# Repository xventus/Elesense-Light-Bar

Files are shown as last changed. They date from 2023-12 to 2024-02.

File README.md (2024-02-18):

# LAMP

Elesense Light Bar is a monitor lamp from [kickstarter](https://www.kickstarter.com/projects/elesense/elesense-computer-monitor-light-bar). Because of the need to control it using a web interface or script and also out of curiosity how it works, this project was created. Take a screwdriver and an anlyzer and see how it works.....  

<table>
    <tr>
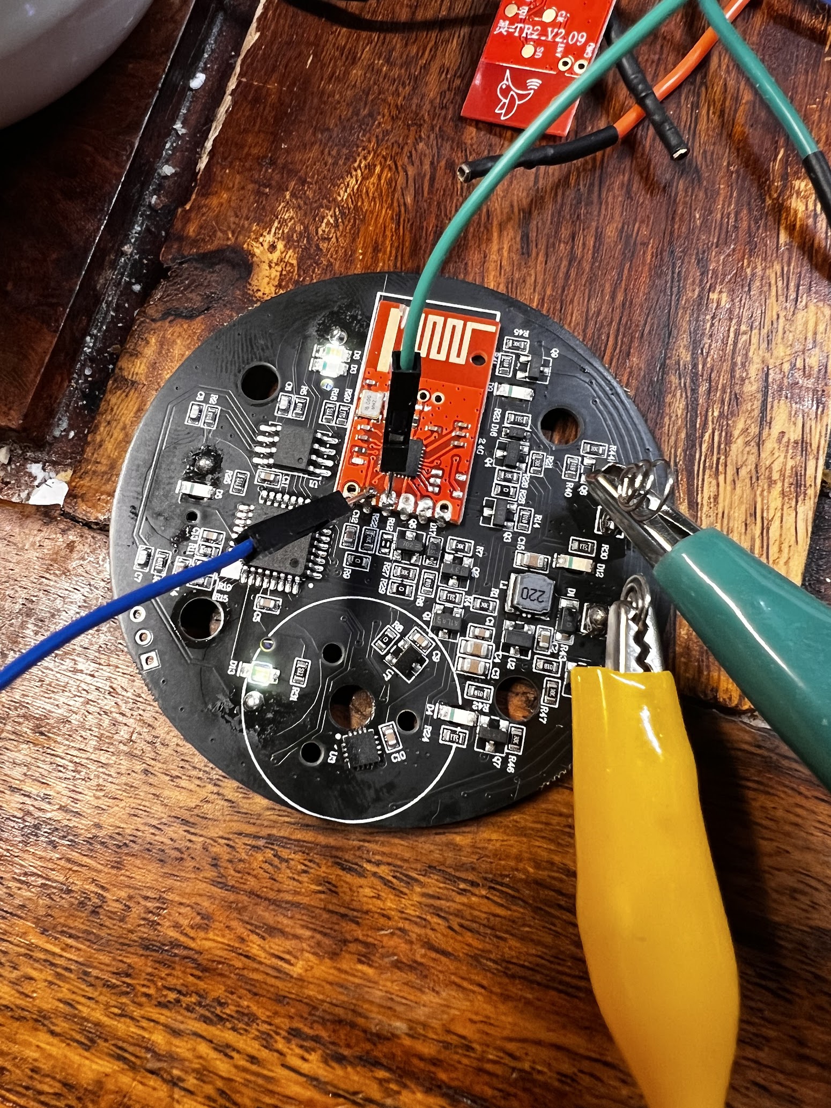
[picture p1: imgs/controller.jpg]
Communication sniffing
        <td></td>
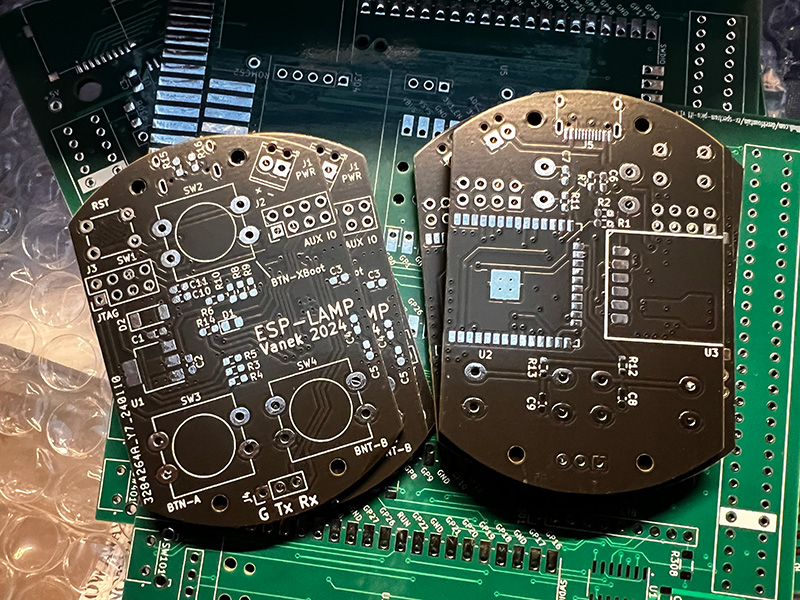
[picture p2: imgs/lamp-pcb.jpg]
PCB
        <td></td>
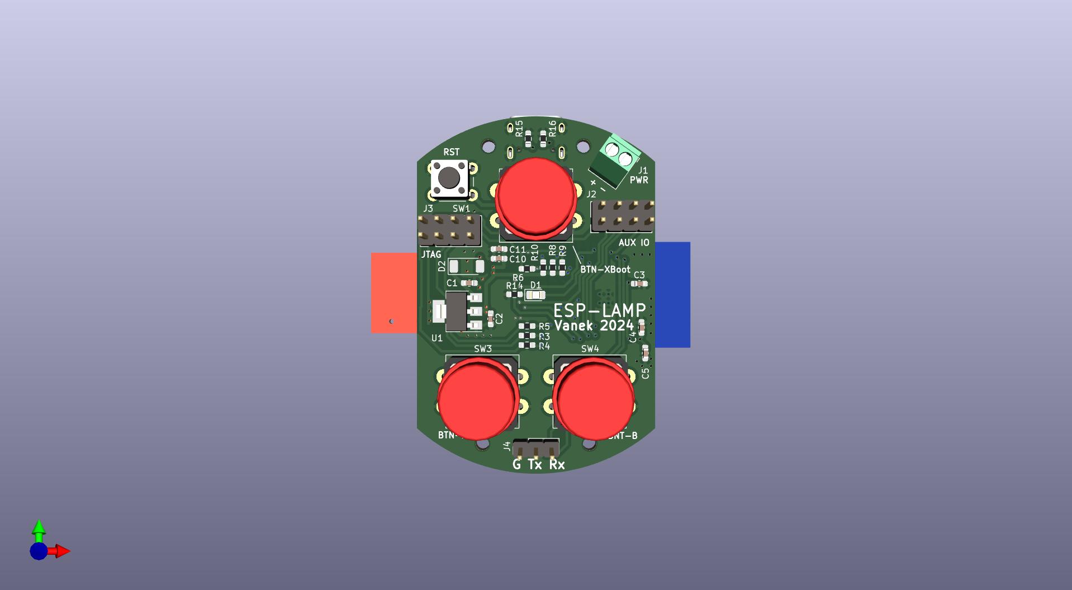
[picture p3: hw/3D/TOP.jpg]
        <td></td>
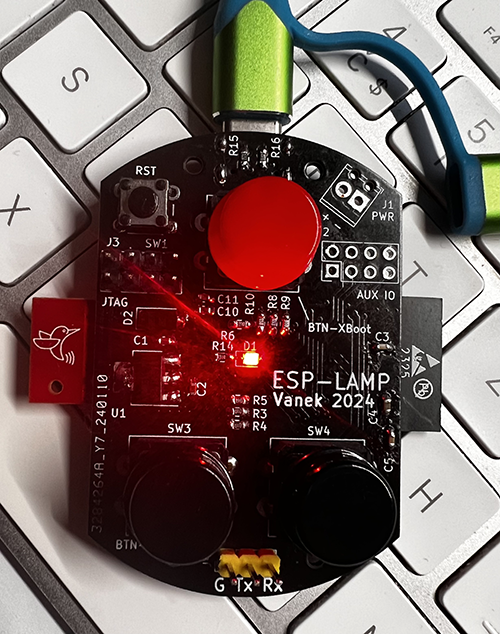
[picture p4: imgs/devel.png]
        <td></td>
    </tr>
</table>

## Hardware
For communication is to use LC12S module communicating on 2.4GHz. It is used as a transparetic serial line at 9600bps. 
For the control of the LAMP project the ESP32 module is used. The development was based on ESP-WROVER-KIT. 

[Wiring the lamp controller based on ESP32](https://github.com/xventus/Elesense-Light-Bar/blob/master/hw/schema.pdf) 

The first version of the board is made. Gerber is in the hw directory. 

[Interactive BOM](https://fotoventus.cz/lamp/ibom.html)

Still in development, custom PCB is being created, will be published in time. 

---
| ESP32 GPIO  | Note |
|---|---|
| GPIO_NUM_25 | LSC12S TX |
| GPIO_NUM_26 | LSC12S RX |
| GPIO_NUM_19 | LSC12S SET |
| GPIO_NUM_18 | LSC12S CS |
| GPIO_NUM_2  | A BUTTON |
| GPIO_NUM_4  | B BUTTON |
| GPIO_NUM_0  | FLASH BUTTON |
| GPIO_NUM_5  | HEART BEAT LED |

## Protocol

sniff

example: 

`0x53 0xC2 0x1C 0x00 0x9D 0x1B 0x00 0x0E 0x01 0x17 0x0E 0x26 0x00` 

---
| Byte position  | Note |
|---|---|
| 0 | header  (always 0x53) |
| 1 | lampID-1  (0xC2) |
| 2 | lampID-2  (0x1C) |
| 3 | lampID-3  (always 0x00) |
| 4 | lampID-4  (0x9D) |
| 5 | lampID-5  (0x1B) |
| 6 | lampID-6 (always 0x00) |
| 7 | lampID-7  (0x0E) (if 0xA4 appears then the rest of the octet is 0x00)  |
| 8 | command  0x01 - ON,  0x10 - OFF, 0x02 - Automatic dimming (0x01) |
| 9 |0x00 - 0x17 intensity (0x00 - min intensity, 0x17 - max intensity), note: when off  0x10 (0x17) |
| 10 |0x00 - 0x17 intensity (0x00 - Yellow MAX, 0x17 - Yellow Min), note: when off 0x10  ([0x0E) | 
| 11 | Checksum  = Sum of [8] + [9] + [10] (0x26) |
| 12 | END mark (always 0x00) |

## HTTP command

LAMP OFF command

`curl -X POST -H "Content-Type: application/json" -d '{"command": "OFF"}' http://xxx.xxx.xxx.xxx/command`

LAMP ON with intensity and hue command

`curl -X POST -H "Content-Type: application/json" -d '{"command": "ON","brightness":"17","hue":"12"}' http://xxx.xxx.xxx.xxx/command`

LAMP get ID & values

`curl http://192.168.2.222/values`

## HW Buttons

---
| Button | Note |
|---|---|
| X-BOOT + reset |  Upoad firmware via serial 
| X-BOOT |  ON / OFF |
| A | Increasing the brightness intensity|
| B | Decreasing the brightness intensity|
| A + B + reset | New initialization, creates a LAM AP and allows you to set up a new WiFi connection | 

## Programming and configuration

Note!!:  Resistor R10 is used on GPIO2, it is necessary to ground it during upload. Press the push button or insert the shorting jumper on the push button.

1. Connect ESP-LAM PCB via 3V3 USB-serial converter to J4 connector
2. Connect power via USB-C connector or via J1
3. Run VisualCode and upload the project
4. In VC Platformio run Build Sytem File Image
5. Press and hold the BTN-XBOOT button and press the RST button, then release RST and BTN-XBOOT 
7. In VC Platformio run Upload Sytem File Image
8. Press and hold the BTN-XBOOT button and press the RST button, then release RST and BTN-XBOOT
9. In VC Platformio, start the Upload Program to ESP
10. Press the RST button, then the LED should start flashing 
11. On your computer, search for the AP named LAMP AP and connect
12. In your web browser enter the address http://192.168.4.1
13. Configure the wifi network and select submit
14. After reboot, ESP-LAMP will connect to your wifi network and you can connect from the browser to the IP address received from DHCP or specified in the configuration and control the lamp.  

## LED STATE

---
| LED | Note |
|---|---|
| .. .. .. |  LAMP runs in AP mode and waits for configuration |
| . -  . - |  The LAMP is waiting to be paired. Please use the original control for the lamp. ESP-LAMP will copy the lamp ID. |
| - - - -  |  LAMP connected to wifi and works |
| . . . . .|  Error |

## Web interface

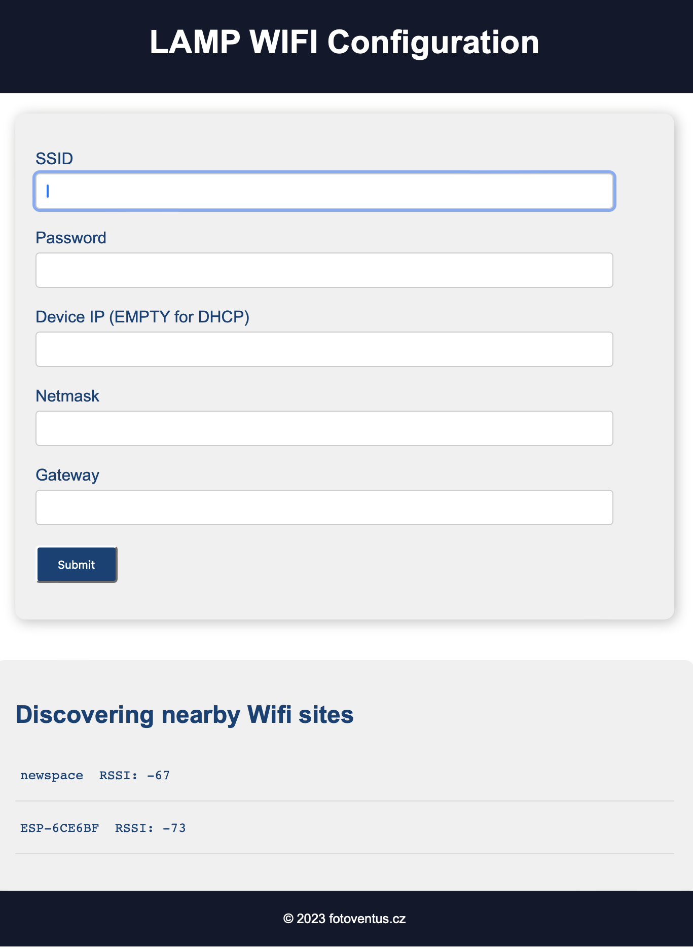
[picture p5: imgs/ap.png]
AP

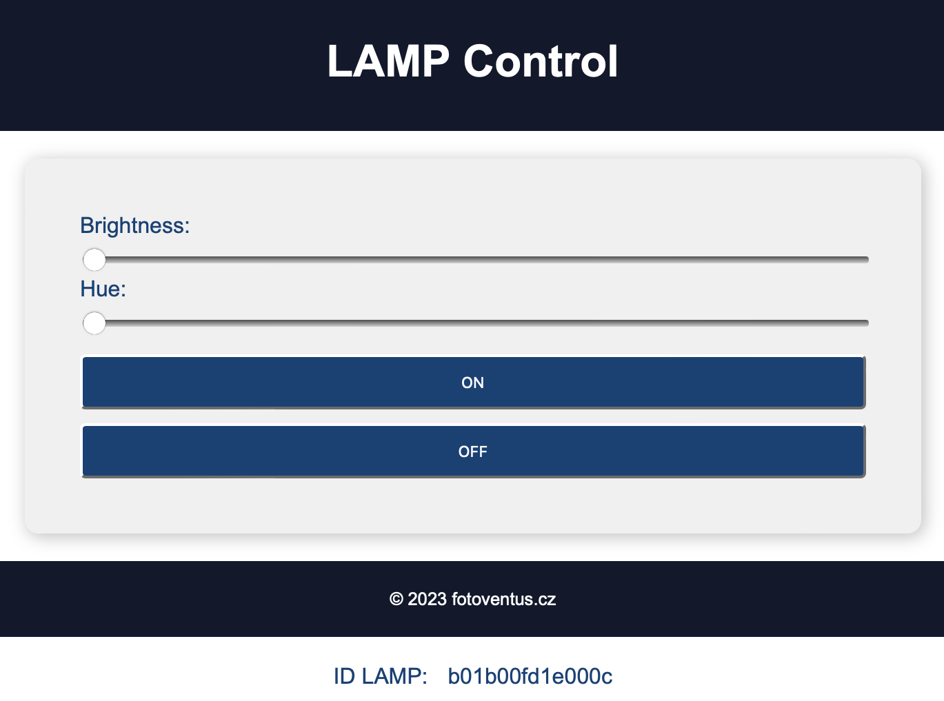
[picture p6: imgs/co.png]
Control


## Case

<table>
    <tr>
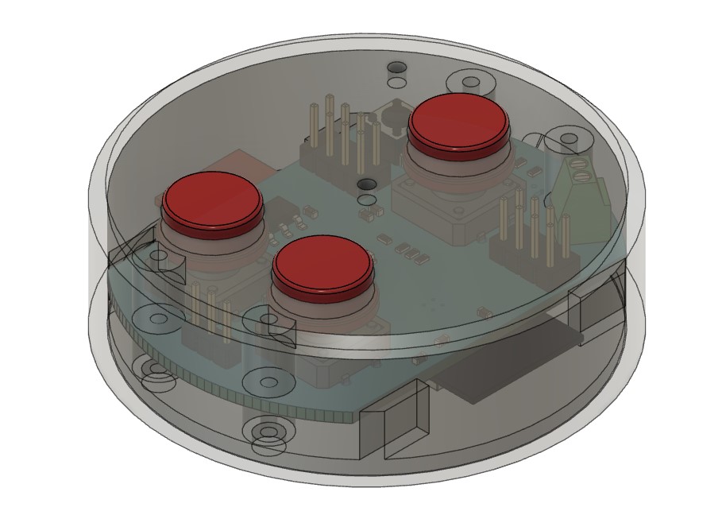
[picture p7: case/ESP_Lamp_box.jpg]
case
        <td></td>
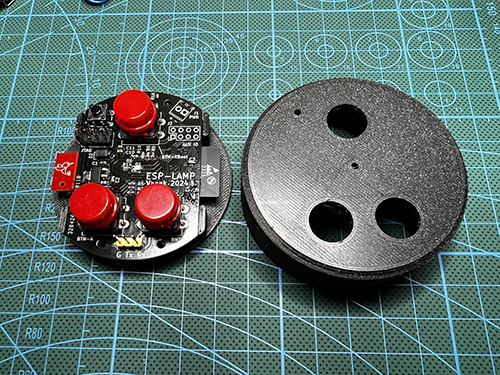
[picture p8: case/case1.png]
case
        <td></td>
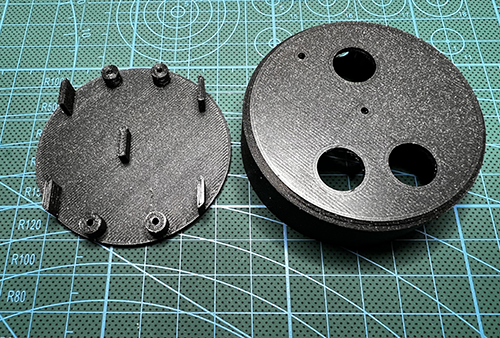
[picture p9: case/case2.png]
case
        <td></td>
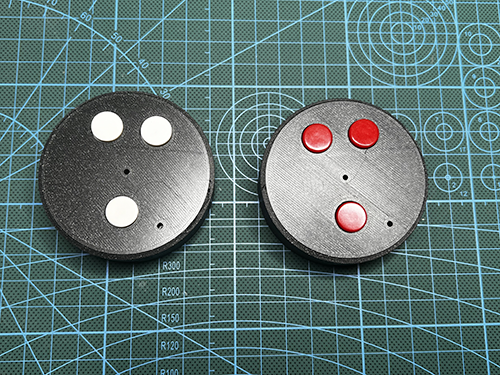
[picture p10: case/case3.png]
case
        <td></td>
    </tr>
</table>

STL files to download for 3D printing of the box. Thanks to [Pavel Vanek](https://github.com/Bobik77)

[STL top part](case/ESP_Lamp_Top_V2.stl)

[STL bottom part](case/ESP_Lamp_Bottom_V2.stl)

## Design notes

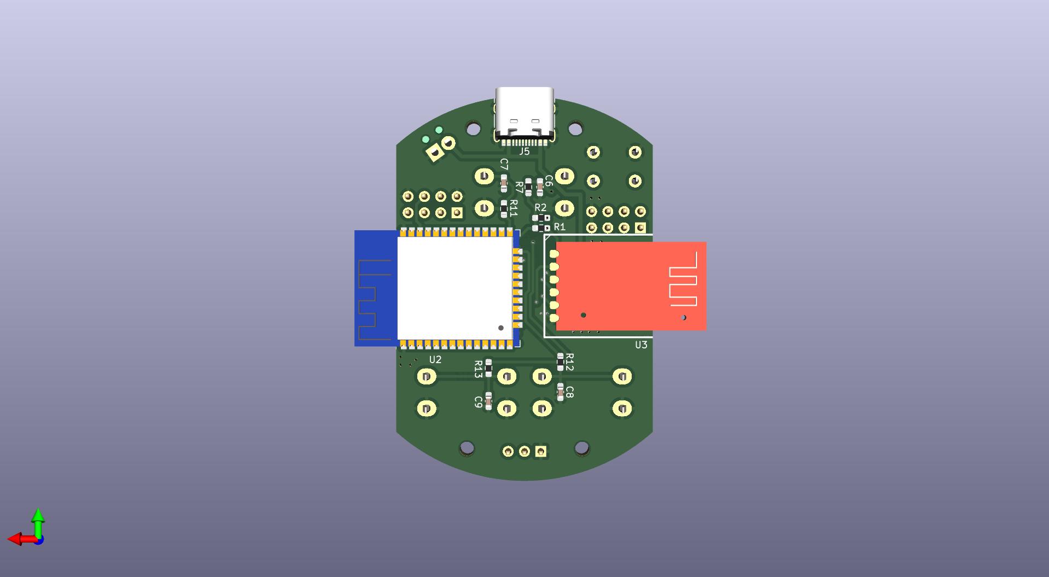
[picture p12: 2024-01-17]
hw/3D/BOT.jpg

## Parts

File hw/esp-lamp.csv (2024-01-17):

Source: | /Users/petrvanek/Documents/GitHub/Elesense-Light-Bar/hw/esp-lamp.kicad_sch
Date: | Wednesday, January 17, 2024 at 02:27:41 PM
Tool: | Eeschema 7.0.10
Generator: | /Applications/KiCad/KiCad.app/Contents/SharedSupport/plugins/bom_csv_grouped_by_value.py
Component Count: | 41
Collated Components:
Item | Qty | Reference(s) | Value | LibPart | Footprint | Datasheet | DNP | Sim.Device | Sim.Pins
1 | 2 | C1, C2 | 22uF | pspice:CAP | Capacitor_SMD:C_0603_1608Metric_Pad1.08x0.95mm_HandSolder | ~
2 | 1 | C3 | 100nF | pspice:CAP | Capacitor_SMD:C_0603_1608Metric_Pad1.08x0.95mm_HandSolder | ~
3 | 1 | C4 | 10uF | pspice:CAP | Capacitor_SMD:C_0603_1608Metric_Pad1.08x0.95mm_HandSolder | ~
4 | 1 | C5 | 100n | pspice:CAP | Capacitor_SMD:C_0603_1608Metric_Pad1.08x0.95mm_HandSolder | ~
5 | 4 | C6, C7, C8, C9 | 1nF | pspice:CAP | Capacitor_SMD:C_0603_1608Metric_Pad1.08x0.95mm_HandSolder | ~
6 | 1 | C10 | 10uF | Device:C | Capacitor_SMD:C_0603_1608Metric_Pad1.08x0.95mm_HandSolder | ~
7 | 1 | C11 | 100nF | Device:C | Capacitor_SMD:C_0603_1608Metric_Pad1.08x0.95mm_HandSolder | ~
8 | 1 | D1 | LED | Device:LED | LED_SMD:LED_0805_2012Metric_Pad1.15x1.40mm_HandSolder | ~
9 | 1 | D2 | 1N4148 | Diode:1N4148 | Diode_SMD:D_SOD-128 | https://assets.nexperia.com/documents/data-sheet/1N4148_1N4448.pdf |  | D | 1=K 2=A
10 | 1 | J1 | Screw_Terminal_01x02 | Connector:Screw_Terminal_01x02 | TerminalBlock_Phoenix:TerminalBlock_Phoenix_MPT-0,5-2-2.54_1x02_P2.54mm_Horizontal | ~
11 | 1 | J2 | Expand | Connector:Conn_01x08_Pin | Connector_PinHeader_2.54mm:PinHeader_2x04_P2.54mm_Vertical | ~
12 | 1 | J3 | JTAG | Connector:Conn_01x08_Male | Connector_PinHeader_2.54mm:PinHeader_2x04_P2.54mm_Vertical | ~
13 | 1 | J4 | Serial | Connector:Conn_01x03_Male | Connector_PinHeader_2.54mm:PinHeader_1x03_P2.54mm_Vertical | ~
14 | 1 | J5 | USB_C_Receptacle_USB2.0 | Connector:USB_C_Receptacle_USB2.0 | Connector_USB:USB_C_Receptacle_HRO_TYPE-C-31-M-12 | https://www.usb.org/sites/default/files/documents/usb_type-c.zip
15 | 4 | R1, R8, R9, R10 | 6k8 | Device:R | Resistor_SMD:R_0603_1608Metric_Pad0.98x0.95mm_HandSolder | ~
16 | 6 | R2, R3, R4, R5, R6, R14 | 100 | Device:R | Resistor_SMD:R_0603_1608Metric_Pad0.98x0.95mm_HandSolder | ~
17 | 4 | R7, R11, R12, R13 | 470 | Device:R | Resistor_SMD:R_0603_1608Metric_Pad0.98x0.95mm_HandSolder | ~
18 | 2 | R15, R16 | 5k1 | Device:R | Resistor_SMD:R_0603_1608Metric_Pad0.98x0.95mm_HandSolder | ~
19 | 1 | SW1 | RESET | Switch:SW_Push | Button_Switch_THT:SW_PUSH_6mm_H4.3mm | ~
20 | 1 | SW2 | X-BOOT | Switch:SW_Push | Button_Switch_THT:SW_PUSH-12mm_Wuerth-430476085716 | ~
21 | 1 | SW3 | A | Switch:SW_Push | Button_Switch_THT:SW_PUSH-12mm_Wuerth-430476085716 | ~
22 | 1 | SW4 | B | Switch:SW_Push | Button_Switch_THT:SW_PUSH-12mm_Wuerth-430476085716 | ~
23 | 1 | U1 | AMS1117-3.3 | Regulator_Linear:AMS1117-3.3 | Package_TO_SOT_SMD:SOT-223-3_TabPin2 | http://www.advanced-monolithic.com/pdf/ds1117.pdf
24 | 1 | U2 | ESP32-WROOM-32 | RF_Module:ESP32-WROOM-32 | RF_Module:ESP32-WROOM-32 | https://www.espressif.com/sites/default/files/documentation/esp32-wroom-32_datasheet_en.pdf
25 | 1 | U3 | LC12S | lc12s:LC12S | lcs:LC12S

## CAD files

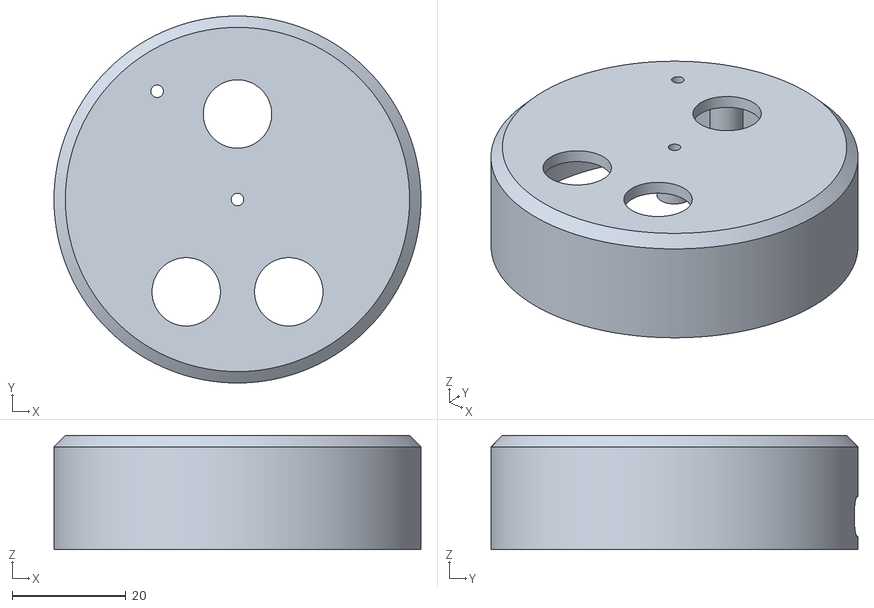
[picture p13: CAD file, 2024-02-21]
case/ESP_Lamp_Top_V3.stl
64.4 x 64.4 x 20.0

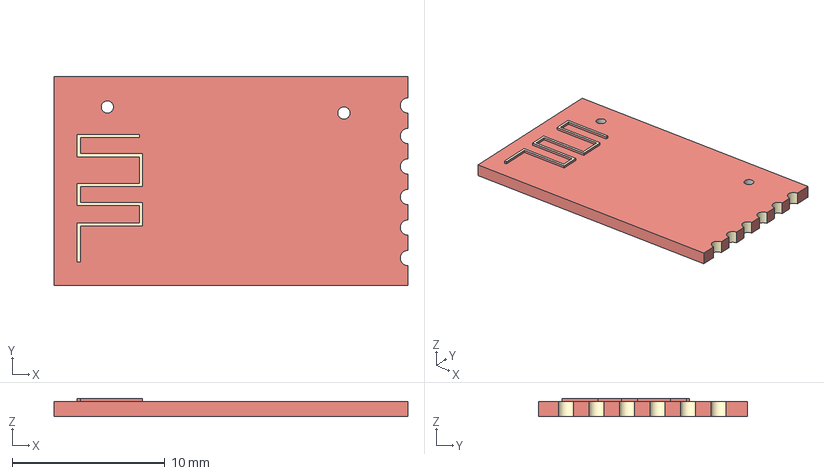
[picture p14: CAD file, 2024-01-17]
hw/3D/LC12S v1.step
23.2 x 13.7 x 1.20 mm

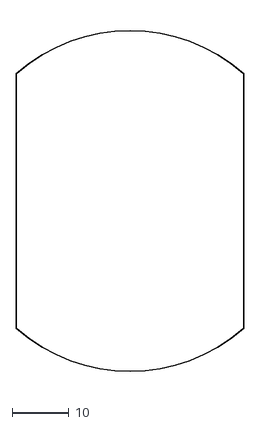
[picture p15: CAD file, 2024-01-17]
hw/OutlineFinal.dxf
40.0 x 65.1

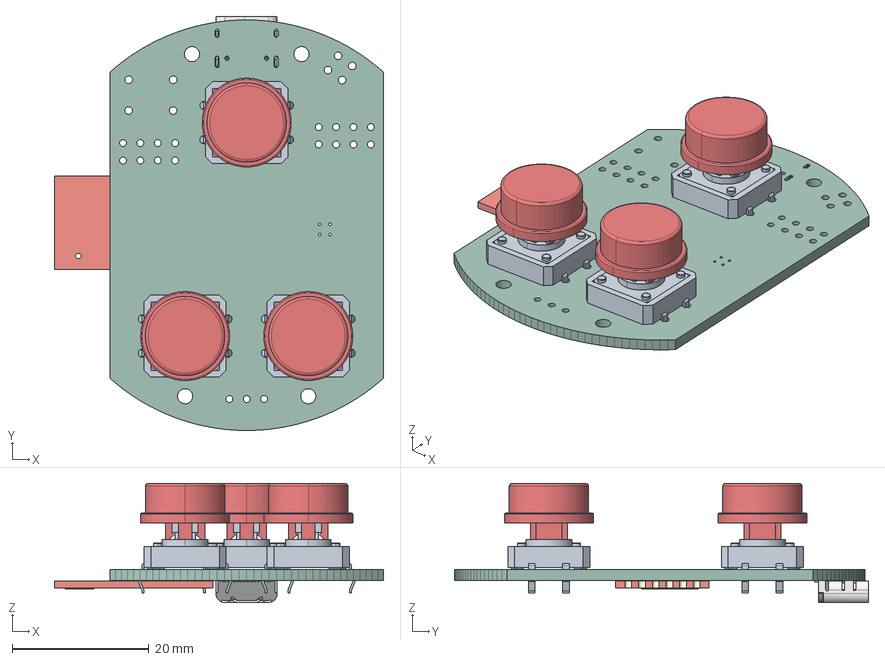
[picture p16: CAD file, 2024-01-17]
hw/3D/esp-lamp.step
48.1 x 60.5 x 17.4 mm
esp-lamp PCB

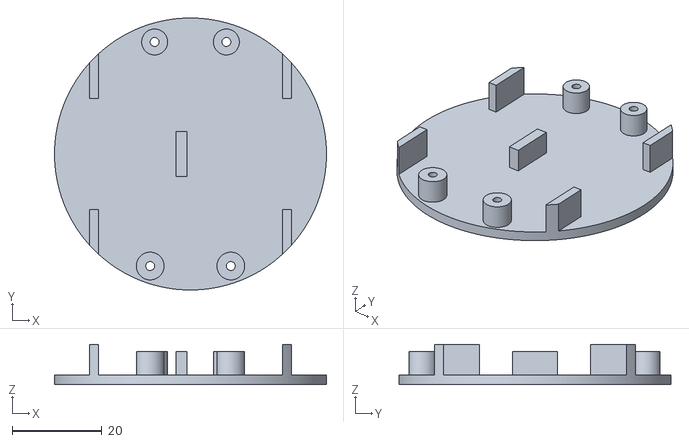
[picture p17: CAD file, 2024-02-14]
case/ESP_Lamp_Bottom_V2.stl
60.7 x 60.7 x 9.01

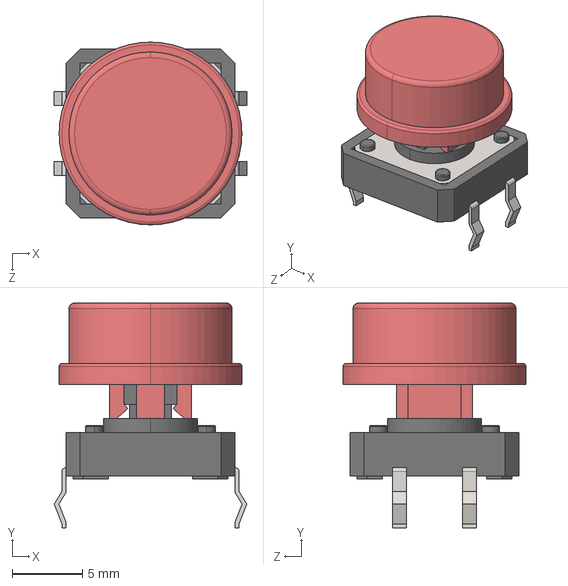
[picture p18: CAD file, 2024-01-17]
hw/3D/12mm Push Button with Cap.STEP
13.7 x 16.0 x 13.0 mm
12mm Push Button
12mm Push Button Cap

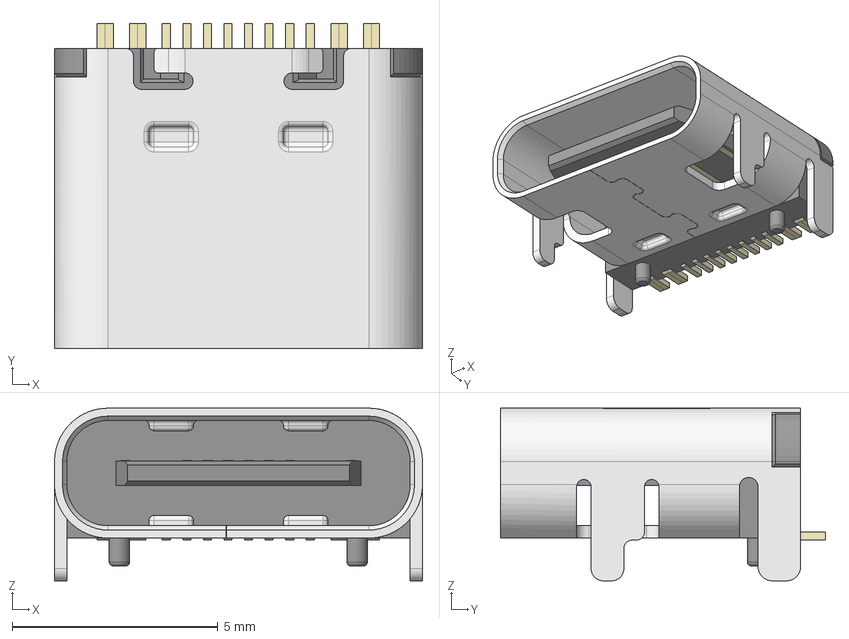
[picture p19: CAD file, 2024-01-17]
hw/3D/HRO_TYPE-C-31-M-12.step
8.95 x 7.90 x 4.20 mm

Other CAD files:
case/ESP_Lamp_Top_V2.stl

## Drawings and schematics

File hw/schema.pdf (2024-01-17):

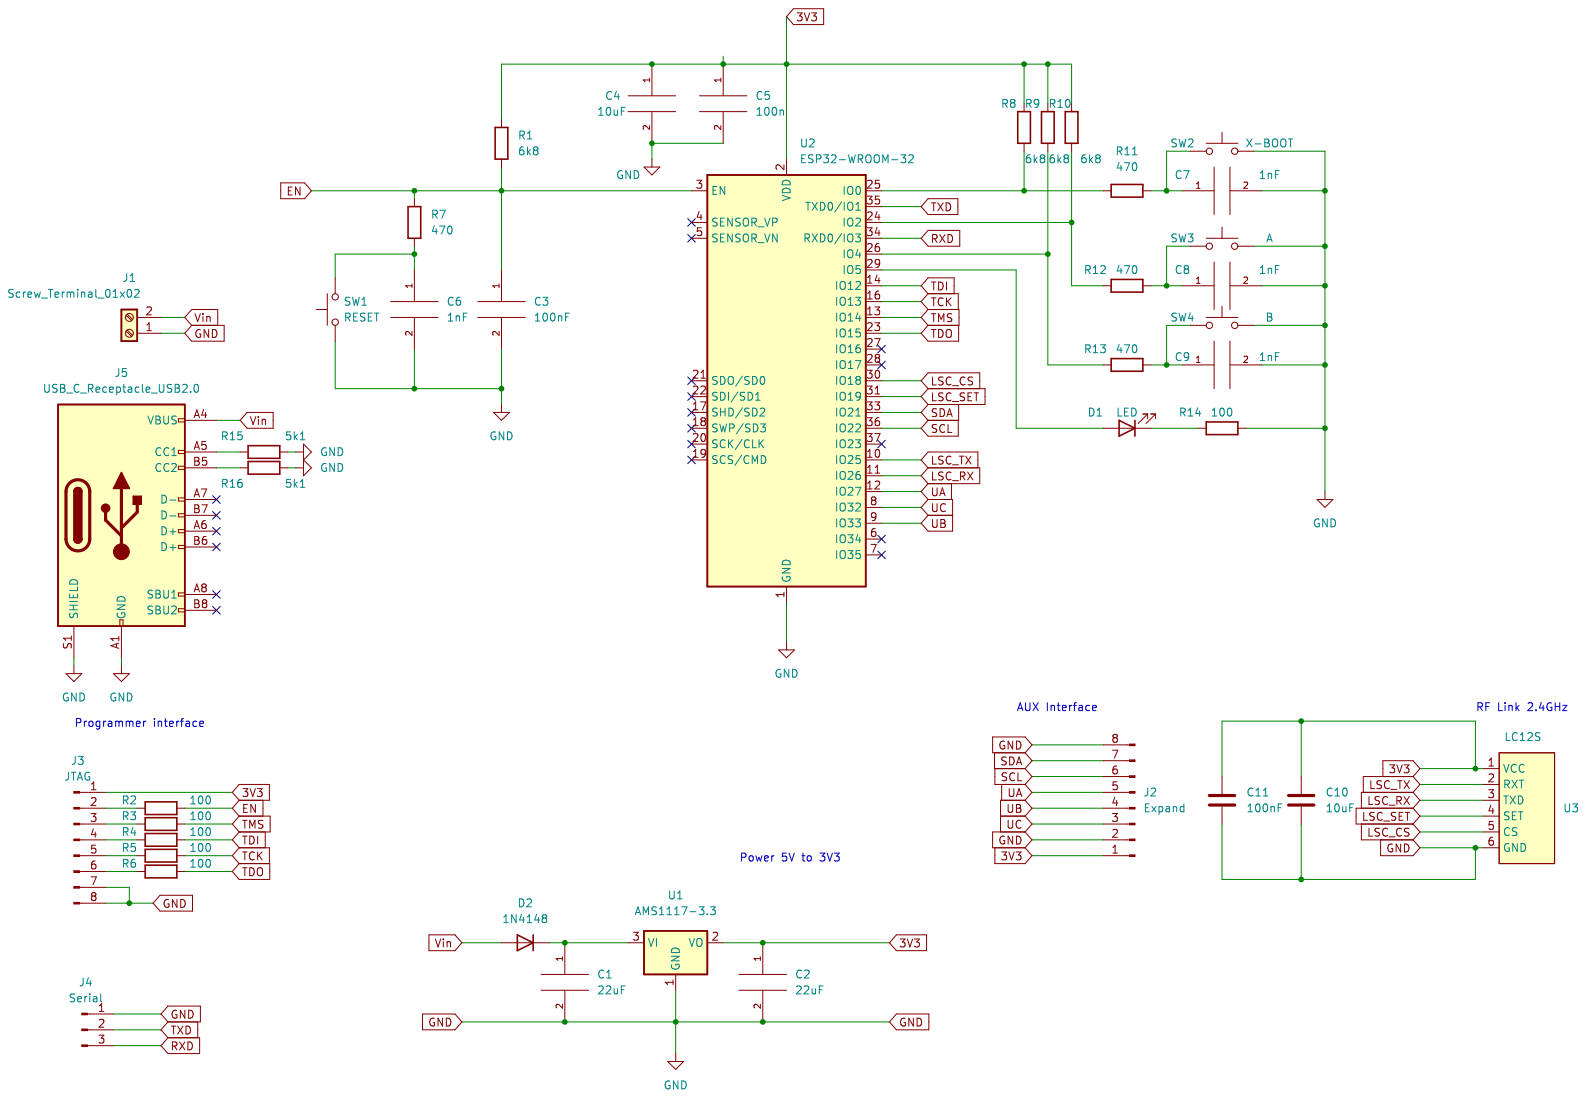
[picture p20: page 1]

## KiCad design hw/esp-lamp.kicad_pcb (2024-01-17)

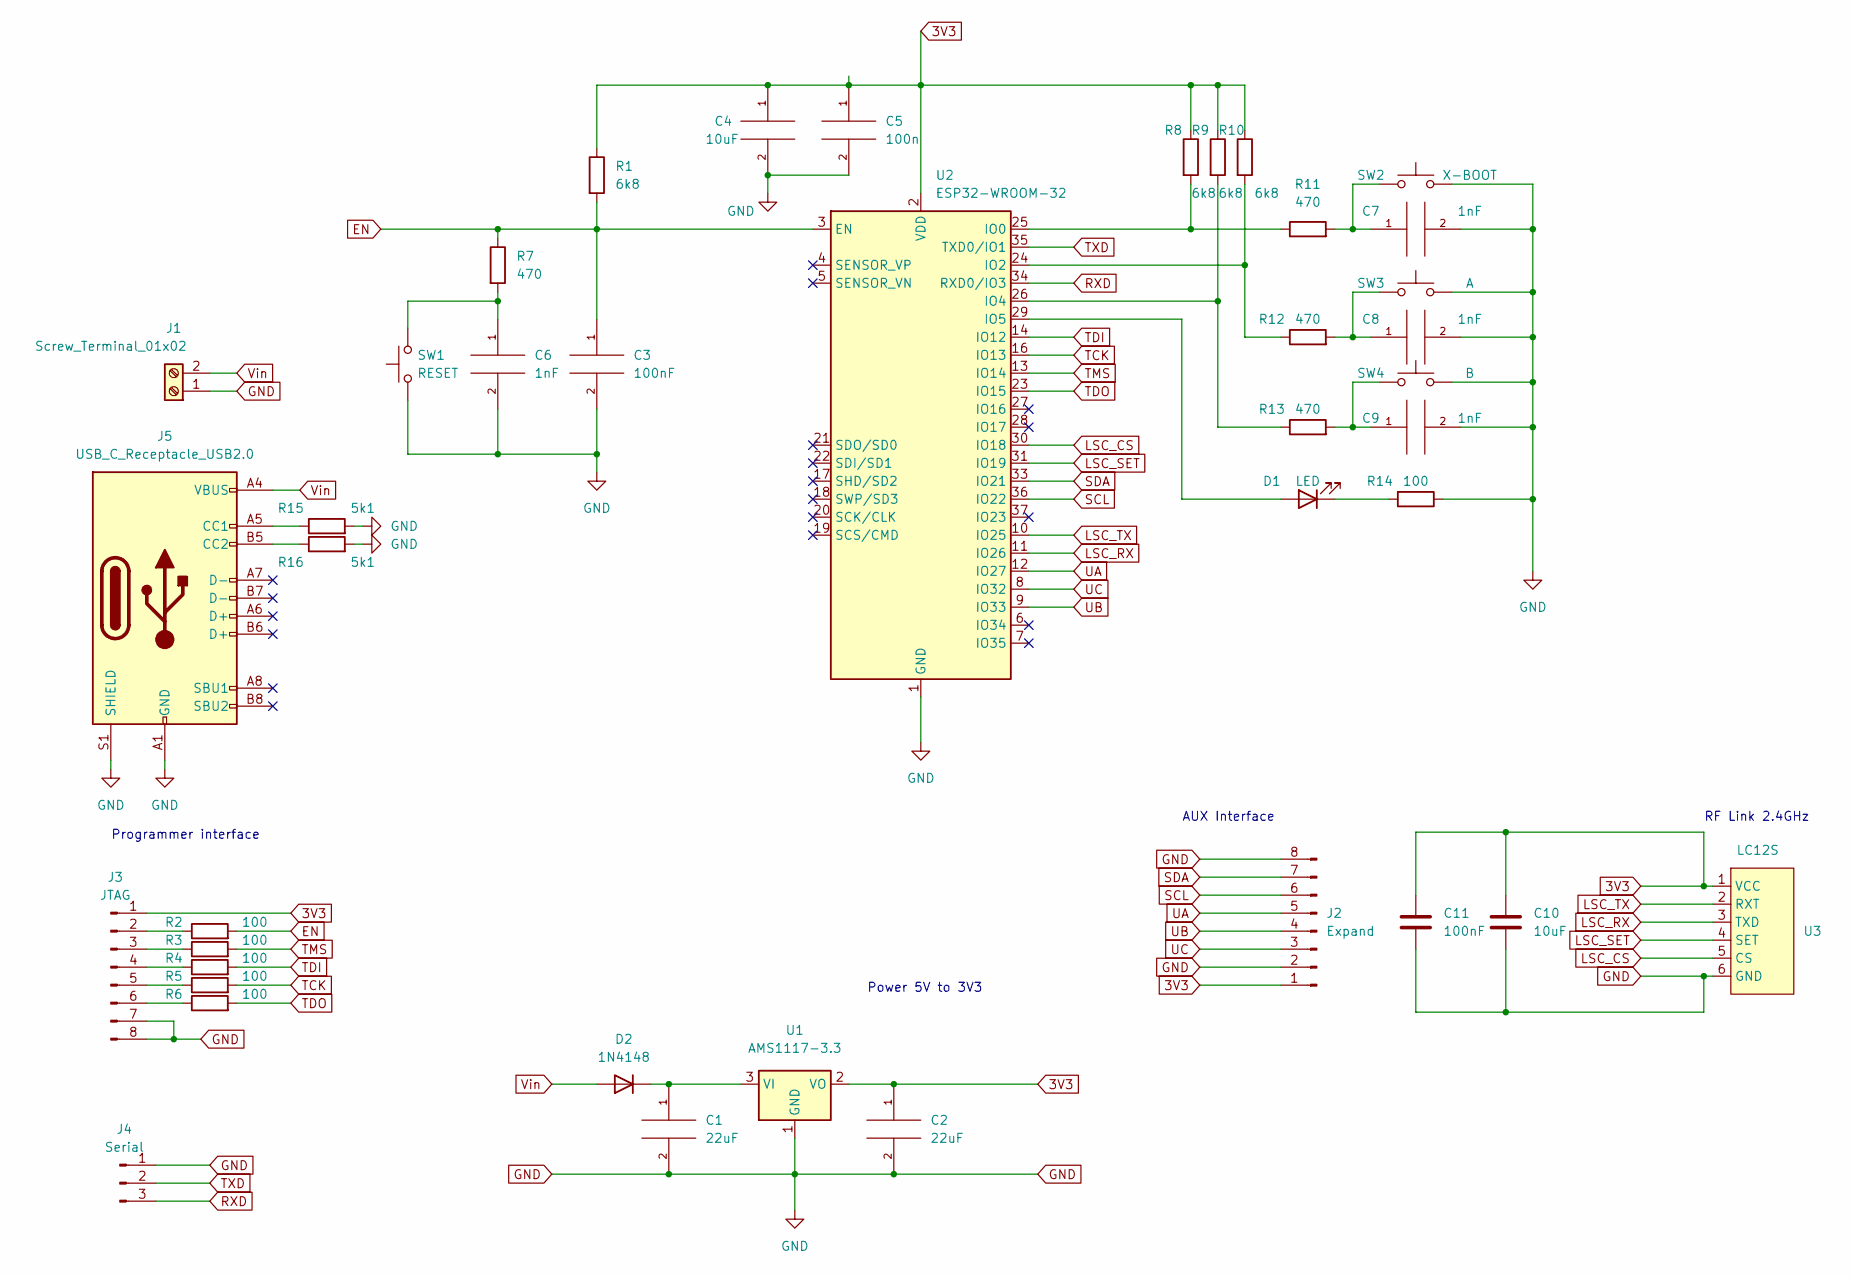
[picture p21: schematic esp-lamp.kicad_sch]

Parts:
C1, C2: 22uF; C_0603_1608Metric_Pad1.08x0.95mm_HandSolder
C3, C11: 100nF; C_0603_1608Metric_Pad1.08x0.95mm_HandSolder
C4, C10: 10uF; C_0603_1608Metric_Pad1.08x0.95mm_HandSolder
C5: 100n; C_0603_1608Metric_Pad1.08x0.95mm_HandSolder
C6, C7, C8, C9: 1nF; C_0603_1608Metric_Pad1.08x0.95mm_HandSolder
D1: LED; LED_0805_2012Metric_Pad1.15x1.40mm_HandSolder
D2: 1N4148; D_SOD-128
J1: Screw_Terminal_01x02; TerminalBlock_Phoenix_MPT-0,5-2-2.54_1x02_P2.54mm_Horizontal
J2: Expand; PinHeader_2x04_P2.54mm_Vertical
J3: JTAG; PinHeader_2x04_P2.54mm_Vertical
J4: Serial; PinHeader_1x03_P2.54mm_Vertical
J5: USB_C_Receptacle_USB2.0; USB_C_Receptacle_HRO_TYPE-C-31-M-12
R1, R8, R9, R10: 6k8; R_0603_1608Metric_Pad0.98x0.95mm_HandSolder
R2, R3, R4, R5, R6, R14: 100; R_0603_1608Metric_Pad0.98x0.95mm_HandSolder
R7, R11, R12, R13: 470; R_0603_1608Metric_Pad0.98x0.95mm_HandSolder
R15, R16: 5k1; R_0603_1608Metric_Pad0.98x0.95mm_HandSolder
SW1: RESET; SW_PUSH_6mm_H4.3mm
SW2: X-BOOT; SW_PUSH-12mm_Wuerth-430476085716
SW3: A; SW_PUSH-12mm_Wuerth-430476085716
SW4: B; SW_PUSH-12mm_Wuerth-430476085716
U1: AMS1117-3.3; SOT-223-3_TabPin2
U2: ESP32-WROOM-32
U3: LC12S

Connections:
3V3: C2.1, C4.1, C5.1, C10.1, C11.1, J2.1, J3.1, R1.1, R8.1, R9.1, R10.1, U1.2 (VO), U2.2 (VDD), U3.1 (VCC)
EN: C3.1, R1.2, R2.2, R7.1, U2.3 (EN)
GND: C1.2, C2.2, C3.2, C4.2, C5.2, C6.2, C7.2, C8.2, C9.2, C10.2, C11.2, J1.1, J2.2, J2.8, J3.7, J3.8, J4.1, J5.A1 (GND), J5.A12 (GND), J5.B1 (GND), J5.B12 (GND), J5.S1 (SHIELD), R14.1, R15.2, R16.2, SW1.1, SW2.2, SW3.2, SW4.2, U1.1 (GND), U2.1 (GND), U2.15 (GND), U2.38 (GND), U2.39 (GND), U3.6 (GND)
LSC_CS: U2.30 (IO18), U3.5 (CS)
LSC_RX: U2.11 (IO26), U3.3 (TXD)
LSC_SET: U2.31 (IO19), U3.4 (SET)
LSC_TX: U2.10 (IO25), U3.2 (RXT)
unnamed: C6.1, R7.2, SW1.2
unnamed: C7.1, R11.2, SW2.1
unnamed: C8.1, R12.2, SW3.1
unnamed: C9.1, R13.2, SW4.1
unnamed: D1.2 (A), U2.29 (IO5)
unnamed: D1.1 (K), R14.2
unnamed: C1.1, D2.1 (K), U1.3 (VI)
unnamed: J3.2, R2.1
unnamed: J3.3, R3.1
unnamed: J3.4, R4.1
unnamed: J3.5, R5.1
unnamed: J3.6, R6.1
unnamed: J5.A5 (CC1), R15.1
unnamed: J5.B5 (CC2), R16.1
unnamed: R8.2, R11.1, U2.25 (IO0)
unnamed: R10.2, R12.1, U2.24 (IO2)
unnamed: R9.2, R13.1, U2.26 (IO4)
RXD: J4.3, U2.34 (RXD0/IO3)
SCL: J2.6, U2.36 (IO22)
SDA: J2.7, U2.33 (IO21)
TCK: R5.2, U2.16 (IO13)
TDI: R4.2, U2.14 (IO12)
TDO: R6.2, U2.23 (IO15)
TMS: R3.2, U2.13 (IO14)
TXD: J4.2, U2.35 (TXD0/IO1)
UA: J2.5, U2.12 (IO27)
UB: J2.4, U2.9 (IO33)
UC: J2.3, U2.8 (IO32)
Vin: D2.2 (A), J1.2, J5.A4 (VBUS), J5.A9 (VBUS), J5.B4 (VBUS), J5.B9 (VBUS)

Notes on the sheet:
AUX Interface
Power 5V to 3V3
Programmer interface
RF Link 2.4GHz

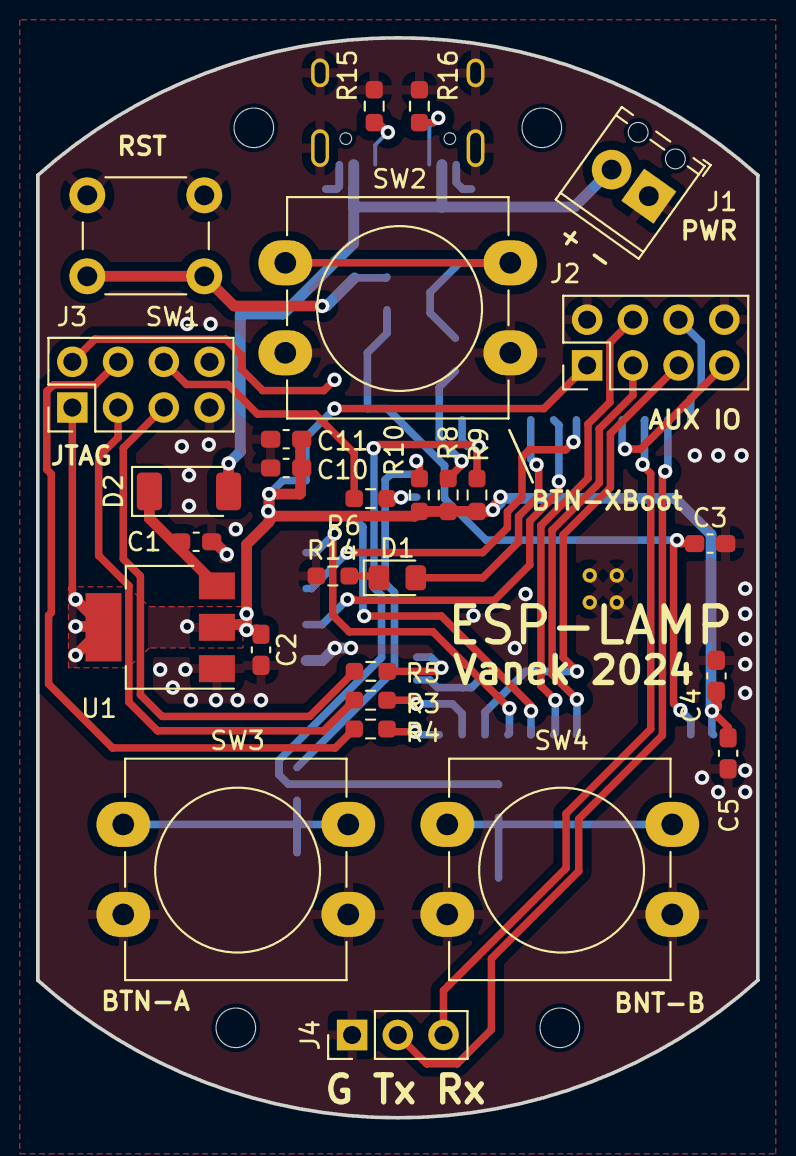
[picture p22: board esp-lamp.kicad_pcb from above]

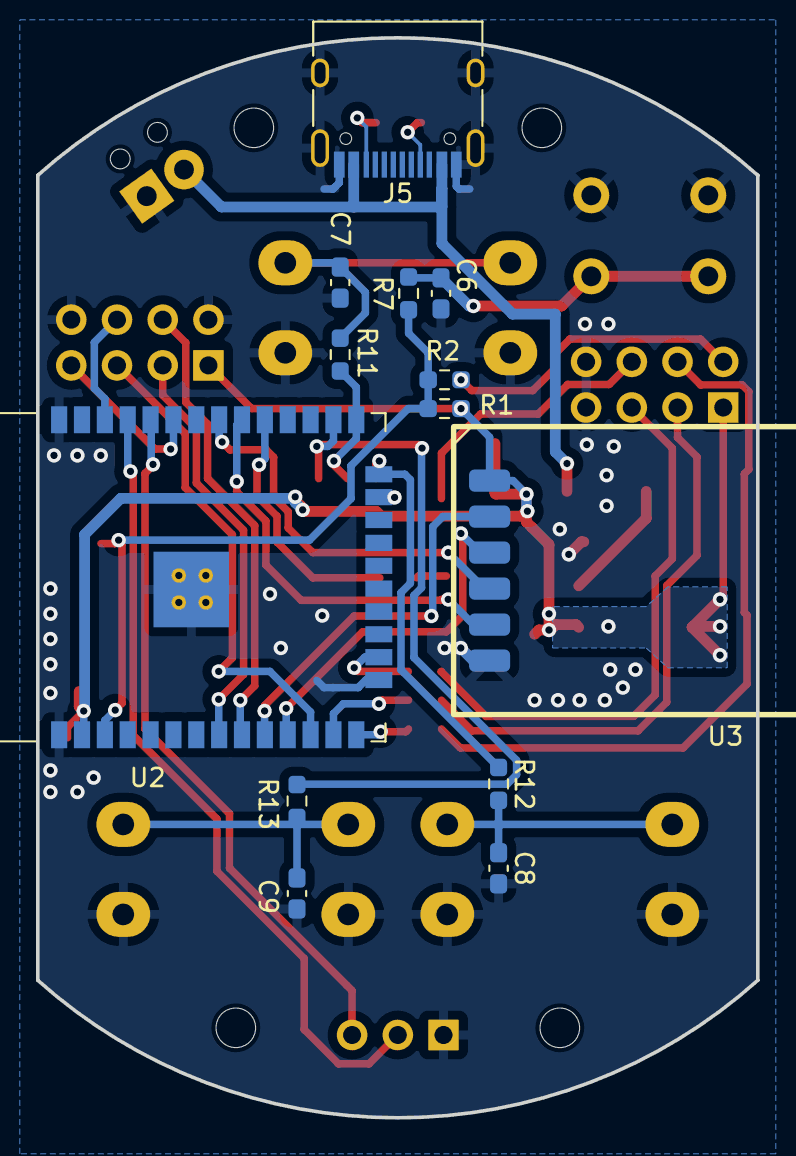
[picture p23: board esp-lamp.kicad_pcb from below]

Board: 2 copper layers, 40.0 x 60.0 mm, 41 parts (13 on the bottom side), 36 nets.

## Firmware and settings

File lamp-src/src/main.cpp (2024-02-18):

//
// vim: ts=4 et
// Copyright (c) 2023 Petr Vanek, petr@fotoventus.cz
//
/// @file   main.cpp
/// @author Petr Vanek

// NOTE: !!!!  Edit  sdkconfig.esp32dev  end set new value --> CONFIG_HTTPD_MAX_REQ_HDR_LEN=1024  !!!!


#include <stdio.h>
#include "application.h"

extern "C" {
    void app_main(void);
}

void app_main() {

    Application::getInstance()->init();
    Application::getInstance()->run();

    return;   
}

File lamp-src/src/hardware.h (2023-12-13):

//
// vim: ts=4 et
// Copyright (c) 2023 Petr Vanek, petr@fotoventus.cz
//
/// @file   hardware.h
/// @author Petr Vanek

#pragma once

#include "driver/gpio.h"
#include "driver/uart.h"

/**
 * @brief Hardware definition, pin assignment, communication interfaces settings
 * 
 */


// LEDs
#define  HEART_BEAT_LED  GPIO_NUM_5

// Buttons
#define  FLASH_BUTTON    GPIO_NUM_0
#define  A_BUTTON        GPIO_NUM_2
#define  B_BUTTON        GPIO_NUM_4

// Serial line to LSC12C
#define LSC_TX_PIN  GPIO_NUM_25 // connect to RX on LSC12C
#define LSC_RX_PIN  GPIO_NUM_26 // connect to TX pin on LSC12C
#define LSC_SET     GPIO_NUM_19 // set mode 
#define LSC_CS      GPIO_NUM_18 // chip select

// USED UART
#define LCS_UART    UART_NUM_1

// Aux free pins - not used 
#define I2C_SDA GPIO_NUM_21
#define I2C_SCL GPIO_NUM_22
#define UA_PIN  GPIO_NUM_27
#define UB_PIN  GPIO_NUM_33
#define UC_PIN  GPIO_NUM_32

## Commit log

2024-01-02 added hardware - schema idea & fix server allocation
    [ESP32-Footprints.kicad_pcb, ESP32-Footprints.sch, esp-lamp.kicad_pcb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]
2024-01-17 finalize pcb
    [12mm Push Button with Cap.STEP, ESP32-Footprints.kicad_pcb, ESP32-Footprints.sch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]
2024-01-17 BOM updated
    [esp-lamp.csv]
2024-02-10 added button task
2024-02-18 Saving parameters to the light when switching off with the HW button.
2024-02-21 cover variant with LED shading
    [ESP_Lamp_Top_V3.stl]
